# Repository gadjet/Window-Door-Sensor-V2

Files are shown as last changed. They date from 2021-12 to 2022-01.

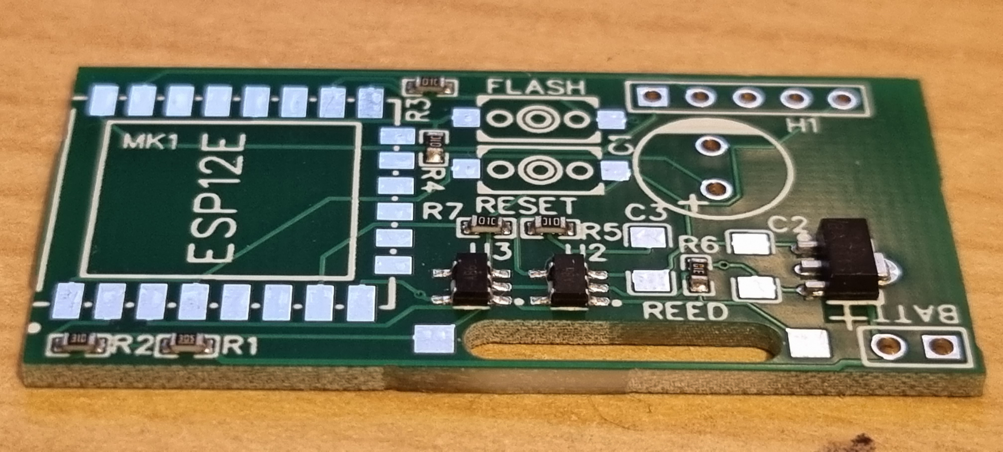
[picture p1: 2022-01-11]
2022-01-05 08.59.07.jpg

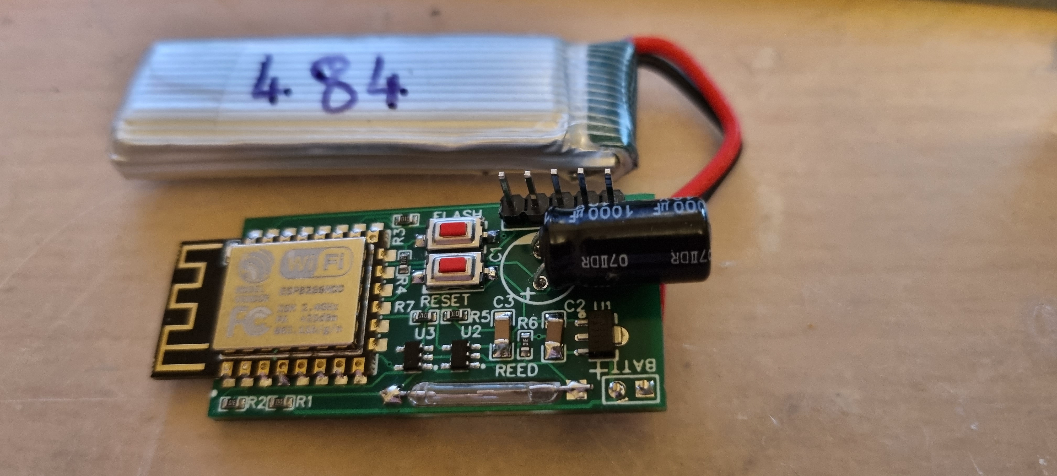
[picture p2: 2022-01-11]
2021-12-23 17.34.26.jpg

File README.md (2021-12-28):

# Window-Door-Sensor-V2
This is the second version of the Window Door sensor transmitter PCB
It uses an ESP 12F and some extrnal logic gates to wake up the ESP from a deep sleep whenever the door is opened or closed.
In my software configuration I use the ESP NOW protocol to send a data packet whenever the ESP is woken up, which takes around 600mS and is received by another ESP that is permenantly powered up.  I have the receiver (WEMOS D1 Mini) connected to the serial port of a Raspberry Pi running Node Red, with Node Red I can direct the message to any number of messaging protocols like email, MQTT. Pushover, pushbullet, Telegram ........ the list goes on.

I have uploaded two sketches, one for the transmitter that is configured for broadcasting to two receivers and one for the Receiver/Bridge connected to my Node Red.

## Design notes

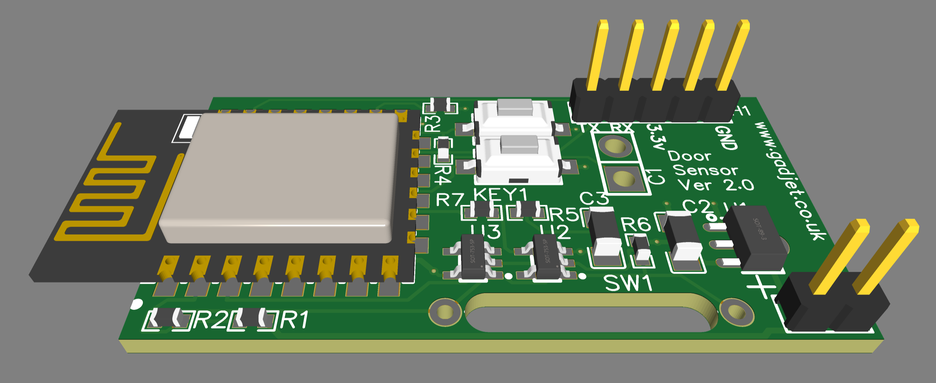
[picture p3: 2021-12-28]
PCB_PCB_Door_Window_Sensor_3D.png

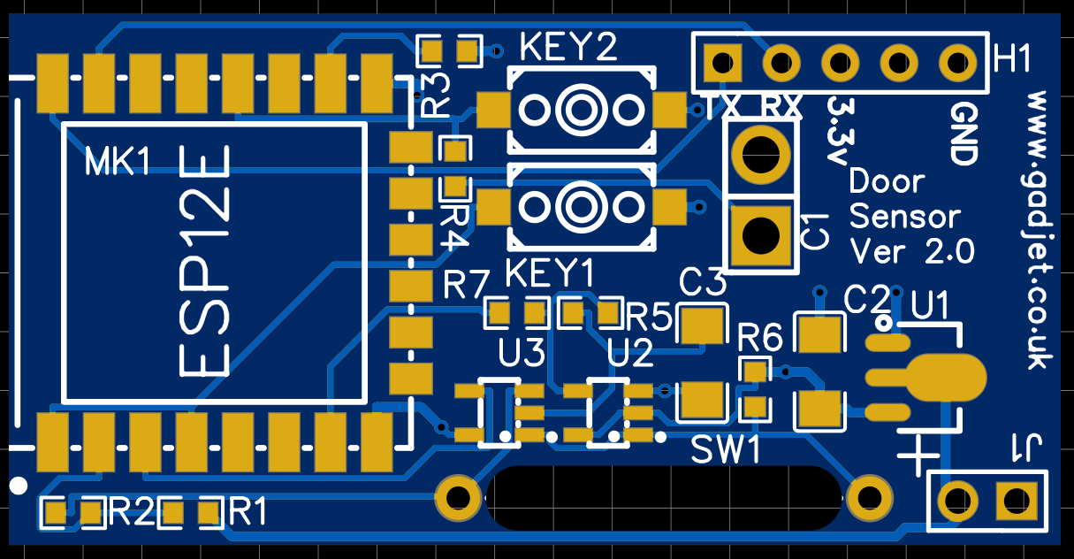
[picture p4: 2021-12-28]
PCB_PCB_Door_Window_Sensor_2021-12-28.png

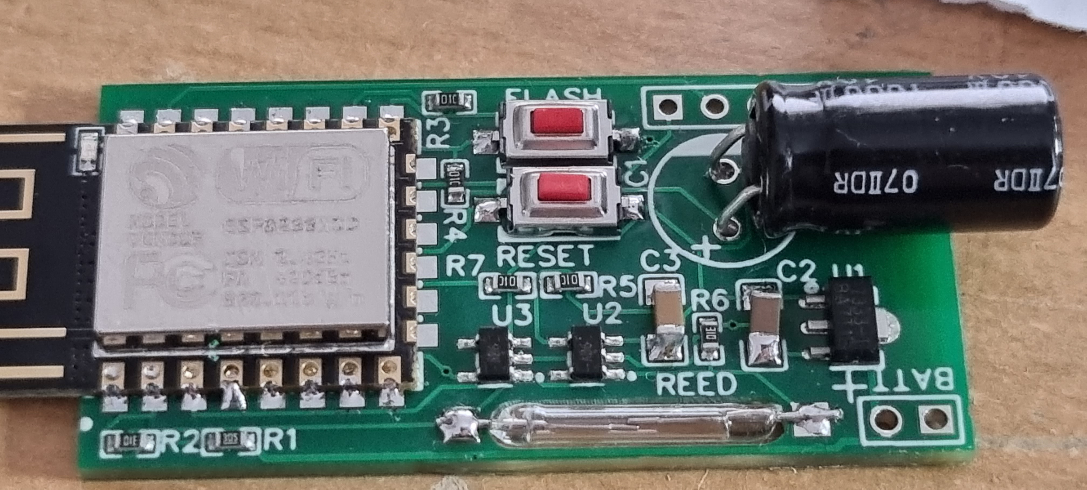
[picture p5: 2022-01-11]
2021-12-21 14.25.37.jpg

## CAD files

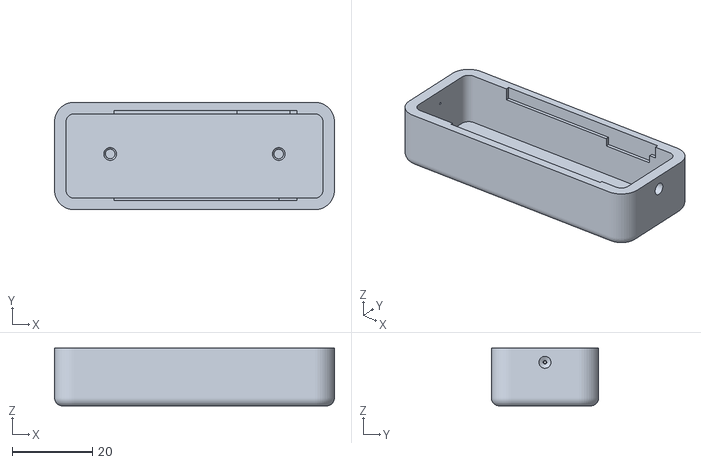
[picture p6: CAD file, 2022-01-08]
Wireless Sensor Housing bottom.stl
69.7 x 26.7 x 14.4

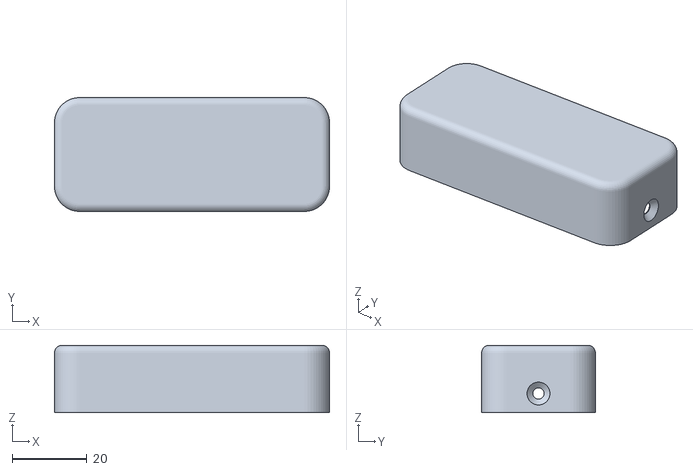
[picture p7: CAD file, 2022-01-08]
Wireless Sensor Housing Top.stl
73.3 x 30.3 x 18.0

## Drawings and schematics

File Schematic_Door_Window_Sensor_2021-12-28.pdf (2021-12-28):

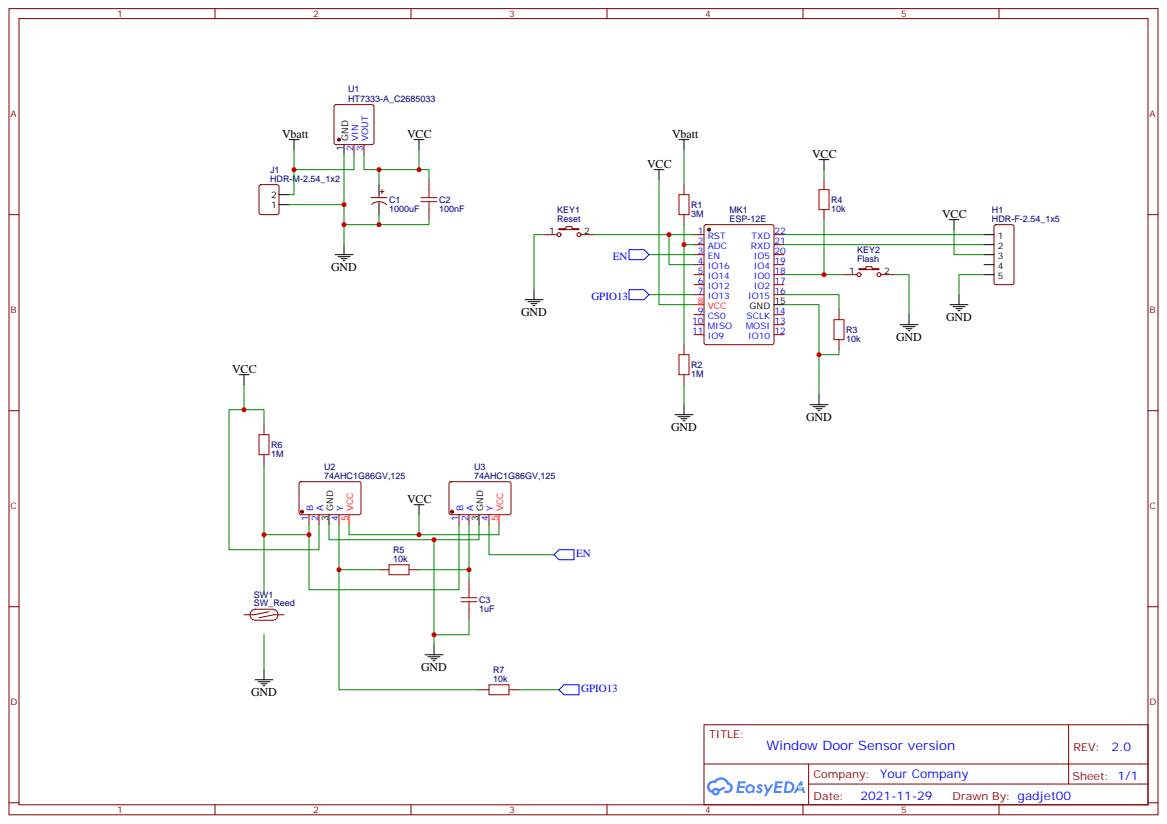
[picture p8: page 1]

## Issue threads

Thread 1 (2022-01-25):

Wakeup

CrackH34D, 2022-01-25:
Hi, I have a question :) you declare the IO16 as a Wakeup pin but are doing the Reset via Power interruption on the EN pin is there a reason for this ? I am just designing on with more functions on an esp32 and I am confused why you chose this way :)

gadjet, 2022-01-25:
Hi,  GPIO16 is used by the code on the ESP to wake itself up by using the ESP. DeepSleep() function whereas the EN pin is toggled via the external logic when the Reed switch opens or closes, in the code I use the DeepSleep doesn't actually wake up the esp but it could.
I hope that answers your question.

CrackH34D, 2022-01-25:
oK thank you, would you look over my Schematic it's my first DIY Board :) [https://prnt.sc/26jb2fz](url)

gadjet, 2022-01-25:
No problem 👍

gadjet, 2022-01-25:
OK I've had a look and I'm not familiar with the esp32 so I can't confirm the functions of the pins but the output of the trigger logic doesn't go to the enable input, is IO35 a wake-up?

Are you using a esp32 module or a chip if it's a module then it may already have pull ups on reset/enable inputs.

Look at using a spx3819 3.3v LDO regulator it can supply 500mA and you may not need the 1000uf cap

gadjet, 2022-01-25:
You don't need a pull down on the output 2Y as the output switches high or low.
The other thing I've found is that with the 1M pull up on the Reed switch it is very sensitive, just touching it causes a trigger when Reed switch is open although in practice the Reed switch will be closed 99% of the time if used on a door or window.
Lowering the resistance would reduce sensitivity but increase power Consumption

gadjet, 2022-01-25:
Standard I2C pull ups are 4k7 not 10k.

gadjet, 2022-01-25:
So I've read that the esp32 uses a different method of waking up instead of two GPIOs connected together it uses an internal rtc timer.

CrackH34D, 2022-01-26:
Thank you for the good look through, chowing a spx3819 is very smart I am considering to use two one for Esp32 chip and the xor gate supply and on wake-up for the sensors , I2C it’s no problem to use 4.7k ore 10k , for the reed switch I now have to chose witch resistor I’ll take do you have a recommendation? The output 2Y is like you said no need for the pull down , for the wake-up on the Esp32 you can use almost every RTC pin :) esp_sleep_enable_ext0_wakeup(GPIO_NUM_X, level)
When I am finished with the project and everything is working I’ll post it on GitHub :)

gadjet, 2022-01-26:
Sounds good, I'm happy to help.
I'm still using the 1M resistor as it will be stuck on a door/window and the input can only be triggered by electrical noise if the door is open and it would only send the same message again "Open".

If I was using this in a different situation and it mattered I would possibly use a 100k or 10k resistor and put up with the extra current draw as it's not going to be alot.

gadjet, 2022-01-26:
BTW I'm going to have to look at using the ESP32s :-)

Closed 2022-01-27.

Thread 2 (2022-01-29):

deeper deep-sleep?

joedupa, 2022-01-29:
Would that be possible to add the "Deeper Deep Sleep" mode to even further decrease the battery consumption? Details here: https://www.youtube.com/watch?v=n_A_8Y4xNx8 or here: https://www.youtube.com/watch?v=pPd362tRx5o

gadjet, 2022-01-30:
I supppose so, I was thinking of something similar but using the enable pin on a different LDO regulator like the SPX3819.
As for the Enable pullup my PCB doesn't use a pullup as it's driven by a logic gate output which is either high or low.

The Irony is that the guy using the ESP to turn itself off uses MQTT to communicate and therefore stays awake for seconds instead of milliseconds therefore probably negating the gains from low sleep current.

joedupa, 2022-02-08:
this looks interesting: https://www.youtube.com/watch?v=Sp8c-d6Scqw

gadjet, 2022-02-08:
Yesi tlooks good but there are a couple of issues,
1. You would have to hold the button down to trigger the supply until the ESP could hold it in and that could take longer than a normal button press .... not sure how much of an issue that would be though.
2. If I understand it, it wouldn't work with a reed switch on a door because it would be permenently powered up as long as the door / window was open whereas the current solution allows for a constant state of the reed switch and the ESP still goes into deep sleep, I have had a door contactoperating for a month and the battery level has gone from 4.1V to 4.0V so far.

I'm working on a three button remote controller using ESP-NOW to control some sockets and I'm using a couple of OR gates and an RC circuit to create a monostable multivibrator that will pulse the enable pin on a LDO regulator for a period (4/500 mS) to powereup the ESP which will then hold on the enable pin until finished then switch off the power, similar to this circuit but using less components.
Also why did he make his circuit so big?

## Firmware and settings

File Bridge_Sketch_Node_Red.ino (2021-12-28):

/*
  Based on a sketch form Rui Santos
  Complete project details at https://RandomNerdTutorials.com/esp-now-many-to-one-esp8266-nodemcu/
  Permission is hereby granted, free of charge, to any person obtaining a copy
  of this software and associated documentation files.
  The above copyright notice and this permission notice shall be included in all
  copies or substantial portions of the Software.
*/

#include <ESP8266WiFi.h>
#include <espnow.h>

float voltage = 0;

// Structure example to receive data
// Must match the sender structure
typedef struct struct_message {
  int id;
  char state[7];
  int vBatt;
} struct_message;

// Create a struct_message called myData
struct_message myData;

// Create a structure to hold the readings from each board
struct_message board1;
struct_message board2;

// Create an array with all the structures
struct_message boardsStruct[2] = {board1, board2};

// Callback function that will be executed when data is received
void OnDataRecv(uint8_t * mac_addr, uint8_t *incomingData, uint8_t len) {
  char macStr[18];
  /*
    Serial.print("Packet received from: ");
    snprintf(macStr, sizeof(macStr), "%02x:%02x:%02x:%02x:%02x:%02x",
           mac_addr[0], mac_addr[1], mac_addr[2], mac_addr[3], mac_addr[4], mac_addr[5]);
    Serial.println(macStr);
    memcpy(&myData, incomingData, sizeof(myData));
    Serial.printf("Board ID %u: %u bytes\n", myData.id, len);
    Serial.print("Door State: ");
    Serial.println(myData.state);
    voltage = myData.vBatt / 10.0;
    Serial.print("Battery Voltage: ");
    Serial.print(voltage,1);
    Serial.println(" Volts");
  */
  //Node red formated serial print, all data in one message
  snprintf(macStr, sizeof(macStr), "%02x:%02x:%02x:%02x:%02x:%02x",
           mac_addr[0], mac_addr[1], mac_addr[2], mac_addr[3], mac_addr[4], mac_addr[5]);
  memcpy(&myData, incomingData, sizeof(myData));
  voltage = myData.vBatt / 10.0;
  Serial.print(myData.id);
  Serial.print(";");
  Serial.print(macStr);
  Serial.print(";");
  Serial.print(myData.state);
  Serial.print(";");
  Serial.println(voltage, 1);
}

void setup() {
  // Initialize Serial Monitor
  Serial.begin(115200);

  // Set device as a Wi-Fi Station
  WiFi.mode(WIFI_STA);
  WiFi.disconnect();

  // Init ESP-NOW
  if (esp_now_init() != 0) {
    Serial.println("Error initializing ESP-NOW");
    return;
  }

  // Once ESPNow is successfully Init, we will register for recv CB to
  // get recv packer info
  esp_now_set_self_role(ESP_NOW_ROLE_SLAVE);
  esp_now_register_recv_cb(OnDataRecv);
}

void loop() {
  // Code here

}

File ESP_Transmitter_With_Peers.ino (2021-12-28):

#include<ESP8266WiFi.h>
#include<espnow.h>

uint8_t bridgeAddress1[] = {0xXX, 0xXX, 0xXX, 0xXX, 0xXX, 0xXX};   //please update this with the MAC address of your ESP-NOW TO MQTT brigde
uint8_t bridgeAddress2[] = {0xXX, 0xXX, 0xXX, 0xXX, 0xXX, 0xXX};   //please update this with the MAC address of your ESP-NOW TO MQTT brigde

// Set your Board ID (ESP32 Sender #1 = BOARD_ID 1, ESP32 Sender #2 = BOARD_ID 2, etc)
#define BOARD_ID 4

const int reedSwitch = 13;

// Structure example to send data
// Must match the receiver structure
typedef struct struct_message {
  int id;
  char state[7];
  int vBatt;
} struct_message;

// Create a struct_message called test to store variables to be sent
struct_message myData;

// Callback when data is sent
void OnDataSent(uint8_t *mac_addr, uint8_t sendStatus) {
  /* Serial.print("\r\nLast Packet Send Status: ");
    if (sendStatus == 0){
     Serial.println("Delivery success");
    }
    else{
     Serial.println("Delivery fail");
    }
  */
}

void setup() {
  // Init Serial Monitor
  //Serial.begin(115200);
  // initialize the reed switch pin as an input:
  pinMode(reedSwitch, INPUT);
  // initialize the wakeup pin as an input:
  pinMode(16, WAKEUP_PULLUP);
  // Set device as a Wi-Fi Station
  WiFi.mode(WIFI_STA);
  WiFi.disconnect();

  // Init ESP-NOW
  if (esp_now_init() != 0) {
    //Serial.println("Error initializing ESP-NOW");
    return;
  }
  // Set ESP-NOW role
  esp_now_set_self_role(ESP_NOW_ROLE_CONTROLLER);

  // Once ESPNow is successfully init, we will register for Send CB to
  // get the status of Trasnmitted packet
  esp_now_register_send_cb(OnDataSent);

  // Register peer
  esp_now_add_peer(bridgeAddress1, ESP_NOW_ROLE_SLAVE, 1, NULL, 0);
  esp_now_add_peer(bridgeAddress2, ESP_NOW_ROLE_SLAVE, 2, NULL, 0);
}

void loop() {
  // Set values to send
  myData.id = BOARD_ID;
  // Read the state of the reed switch and send open or closed
  if (digitalRead(reedSwitch) == HIGH) {
    strcpy(myData.state, "Closed");
  }
  else {
    strcpy(myData.state, "Open");
  }

  myData.vBatt = (analogRead(A0) * 4.2 * 10 / 1023);
  // Send message via ESP-NOW
  esp_now_send(0, (uint8_t *) &myData, sizeof(myData));
  ESP.deepSleep(0);
  delay(200);
}

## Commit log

2022-01-08 Add files via upload
    STL files for a housing
    [Wireless Sensor Housing Top.stl, Wireless Sensor Housing bottom.stl]
2022-01-11 Add files via upload
    Some pictures of the sensor at different stages
2022-01-11 Add files via upload
    image of the sensor PCB
